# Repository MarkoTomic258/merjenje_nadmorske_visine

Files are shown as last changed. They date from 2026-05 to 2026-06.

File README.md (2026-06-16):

# Naprava za merjenje nadmorske višine 

## Opis projekta
Ustvarila sva napravo za merjenje nadmorske višine. Uporabila sva senzor BME280, ki s pomočjo meritev temperature, vlage in tlaka prek programske kode izračuna nadmorsko višino. Na LCD-zaslonu se izpisujejo nadmorska višina ter vsi podatki, ki vplivajo na njen izračun (temperatura, vlaga in tlak).

## Kosovnica
* Arduino UNO
* LCD 20x4
* BME280 senzor
* Stikalo za vklop/izklop
* Baterijski konektor
* Baterija
* Hitra sponka
* Povezovalne žičke

## Vezalna shema
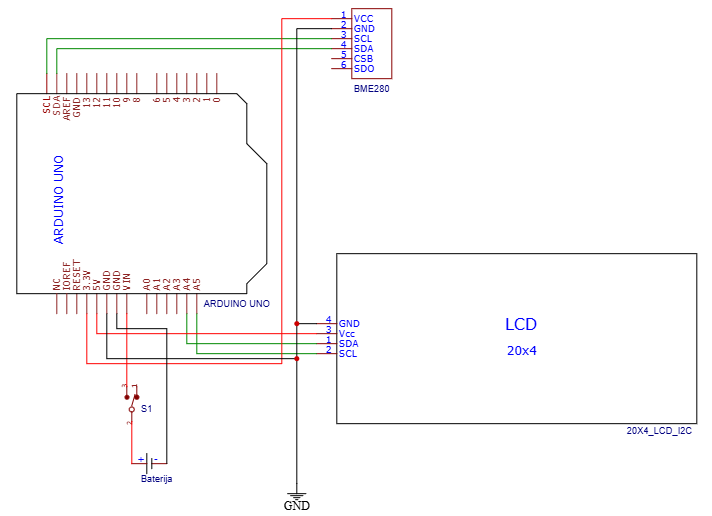
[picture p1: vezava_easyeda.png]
Vezava


## Načrt ohišja

### Škatla
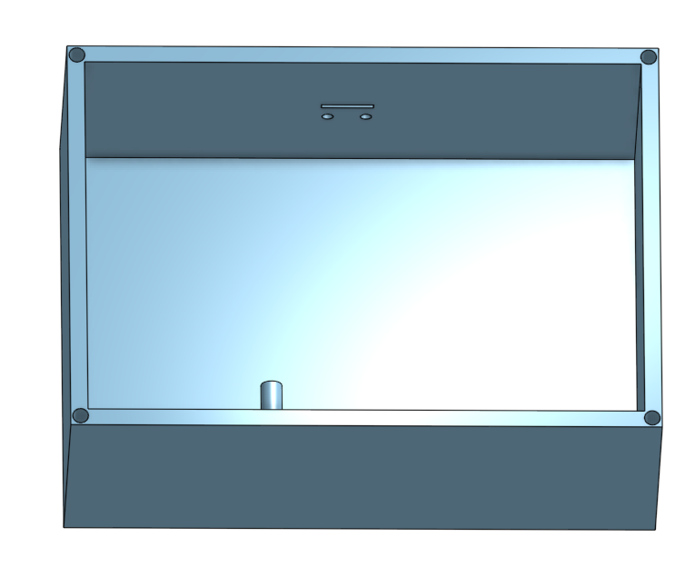
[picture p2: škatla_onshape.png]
Ohišje


STL file: [Klikni me](stl_škatla.stl)

### Pokrov
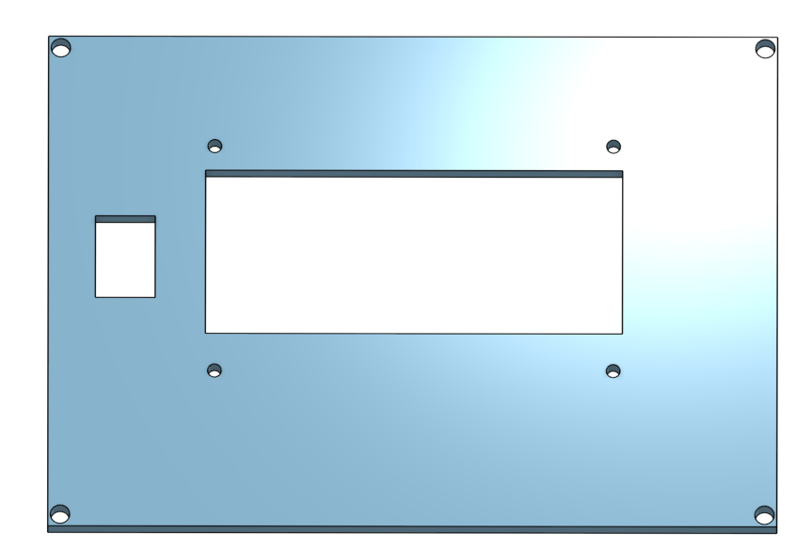
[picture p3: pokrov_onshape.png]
Pokrov


STL file: [Klikni me](stl_pokrov.stl)

### Ohišje za senzor
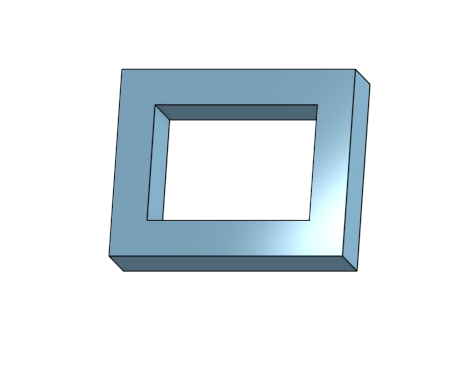
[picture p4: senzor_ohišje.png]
Senzor


STL file: [Klikni me](stl_senzor.stl)

### Izračuni in enačbe
Za izdelavo najine vezave nisva potrebovala komponent, ki bi potrebovale enačbe in izračune.

## Programska koda
Koda se nahaja tu:  [Klikni me](arduino_koda.ino)

## Videoposnetek delovanja
https://github.com/user-attachments/assets/02deefcb-a9b5-40ab-951b-67d8feb4908a

Posnetek si lahko ogledate tudi na YouTubu: [Klikni me](https://youtube.com/shorts/nMZC6nQ5Q0s?feature=share)

## A-test
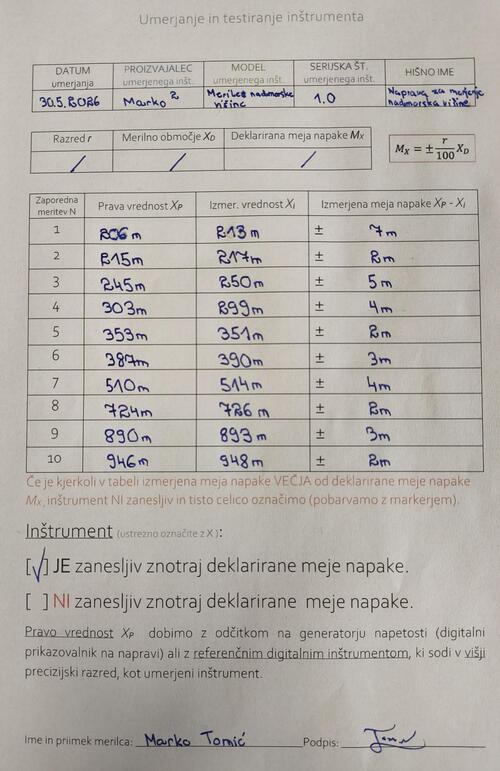
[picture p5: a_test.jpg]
Atest


Največje odstopanje pri meritvah je bilo ± 3,3 %.

## Komentar
Merilna naprava deluje stabilno in v skladu s pričakovanji, meja napake pa je v mejah normale. Meritve so bile opravljene, ko je bil zračni tlak približno 1022 hPa. Ker je bil zračni tlak v času kalibracije blizu standardne vrednosti, so izračuni nadmorske višine natančni. Z vezavo sva imela veliko težav, saj so se žičke večkrat staknile, zato sva težavo rešila tako, da sva uporabila večpinske konektorje za Arduino žičke. Težave sva imela tudi s povezovanjem ozemljitev (GND), kjer sva potrebovala originalno hitro sponko, da je vezava delovala, kot bi morala. Mere modela ohišja Onshape so bile natančno izmerjene, razen prostor za senzor je bil premajhen, zato sva morala ta prostor razširiti/zbrusiti, da se je senzor lepo vmestil v ohišje. Prav tako sva dodala še posebno ohišje okoli senzorja za boljšo varnost in zaščito pri udarcu ob tla.

## Izboljšave
Za izboljšavo merilnika nadmorske višine bi lahko dodala gumba za kalibracijo zračnega tlaka v realnem času, uvedla programsko glajenje podatkov z drsnim povprečjem ali napravo opremila z GPS modulom in MicroSD kartico za beleženje poti.

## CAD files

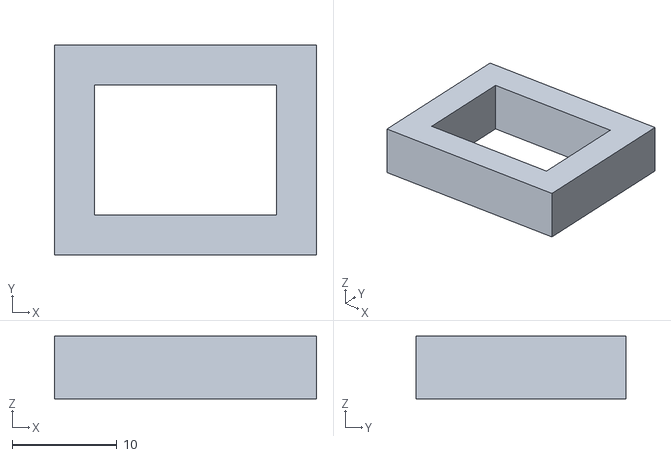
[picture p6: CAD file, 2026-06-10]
stl_senzor.stl
25.0 x 20.0 x 6.00

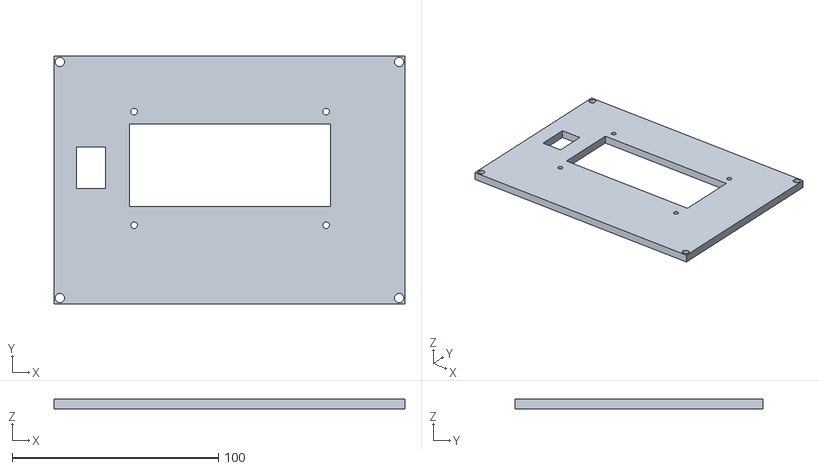
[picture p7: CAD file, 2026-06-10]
stl_pokrov.stl
170.0 x 120.0 x 5.00

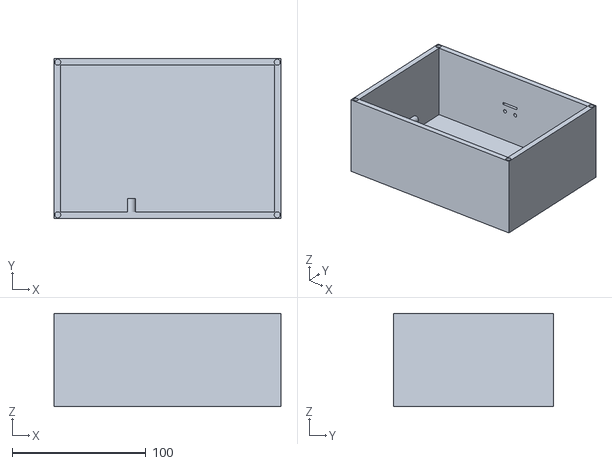
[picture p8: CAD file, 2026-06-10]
stl_škatla.stl
170.0 x 120.0 x 70.0

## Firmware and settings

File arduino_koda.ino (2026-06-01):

#include <Wire.h>
#include <Adafruit_Sensor.h>
#include <Adafruit_BME280.h>
#include <LiquidCrystal_I2C.h>

#define SEALEVELPRESSURE_HPA (1022)

Adafruit_BME280 bme;
LiquidCrystal_I2C lcd(0x27, 20, 4);

void setup() {
  lcd.init();
  lcd.backlight();

  if (!bme.begin(0x76)) {
    lcd.print("BME280 error!");
    while (1);
  }
  
  lcd.setCursor(0, 0); lcd.print("TEMP:");
  lcd.setCursor(0, 1); lcd.print("VLAGA:");
  lcd.setCursor(0, 2); lcd.print("TLAK:");
  lcd.setCursor(0, 3); lcd.print("VIS.:");
}

void loop() {
  float temp   = bme.readTemperature();
  float tlak   = bme.readPressure() / 100.0F;
  float vlaga  = bme.readHumidity();
  float visina = bme.readAltitude(SEALEVELPRESSURE_HPA);

  // Vrstica 1: Temperatura
  lcd.setCursor(11, 0);
  if (temp < 10 && temp >= 0) lcd.print(" ");
  lcd.print(temp, 1); lcd.print(" "); lcd.print((char)223); lcd.print("C");

  // Vrstica 2: Vlaga
  lcd.setCursor(11, 1);
  if (vlaga < 100) lcd.print(" ");
  if (vlaga < 10)  lcd.print(" ");
  lcd.print(vlaga, 1); lcd.print(" %");

  // Vrstica 3: Tlak (hPa)
  lcd.setCursor(9, 2); 
  if (tlak < 1000) lcd.print(" ");
  lcd.print(tlak, 1); lcd.print(" hPa");

  // Vrstica 4: Nadmorska višina
  lcd.setCursor(12, 3);
  if (visina < 1000 && visina >= 0) lcd.print(" ");
  if (visina < 100 && visina >= 0)  lcd.print(" ");
  lcd.print(visina, 0); lcd.print(" m ");

  delay(2000);
}
